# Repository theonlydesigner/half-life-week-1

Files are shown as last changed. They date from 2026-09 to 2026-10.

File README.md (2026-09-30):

# week 1: rp2040 dev board & mini hackpad

## project goals
* **Target Specs:** custom RP2040 microcontroller board using the QFN-56 package, 16MB QSPI flash, 12MHz crystal oscillator, USB-C connector with 5.1k CC pull-down resistors, and dual-row breakout headers for all GPIO pins to drive a mini hackpad.
* **Design Philosophy:** build a functional dev board from absolute ground zero using the hack club stasis guide so i finally understand what goes on under the hood of a raspberry pi pico [instead of treating microcontrollers like magic black boxes].
* **Why I'm building this:** week 1 theme is PCB, and i needed a custom board to integrate with an old mini hackpad design i had lying around. also i wanted to suffer through routing 0402 passives and tiny IC pins.

## bill of materials (BOM)
* refer to `bom.csv` in this folder for the full list of parts including the RP2040 MCU, W25Q128 flash chip, LDO voltage regulator, buttons, and passive components.

## dev journal - part 6: left-side GPIO routing (the lost footage)
* **Time spent:** 2 hours
* **Recorded on lapse:** no [because my brain shut off and i forgot to hit record]

this was easily the most painful part of the entire week. of course, this is the exact 2-hour block where i forgot to start the lapse recording, so you'll just have to take my word for it that i was working and not staring blankly at a wall.

since this was my first time designing an RP2040 board from scratch, trying to connect the RP2040 pins to the left-side GPIO headers turned into a complete trace-routing nightmare. i was following the hack club stasis guide (`stasis.hackclub.com/starter-projects/devboard`), but making clean connections for GPIO0 through GPIO15 without crossing traces or creating illegal angles felt like playing a high-stakes game of snake. 

i had to pause every 5 minutes to watch multiple youtube tutorials on KiCad trace routing, net classes, and how to use vias without making the PCB look like cheese. i kept triggering Design Rule Check (DRC) errors because my traces were either too close to the ground plane or running over decoupling capacitors. after two hours of tearing my hair out, re-routing lines three times over, and wrestling with via placements, the left side is finally connected and fully routed. 

## visual showcase

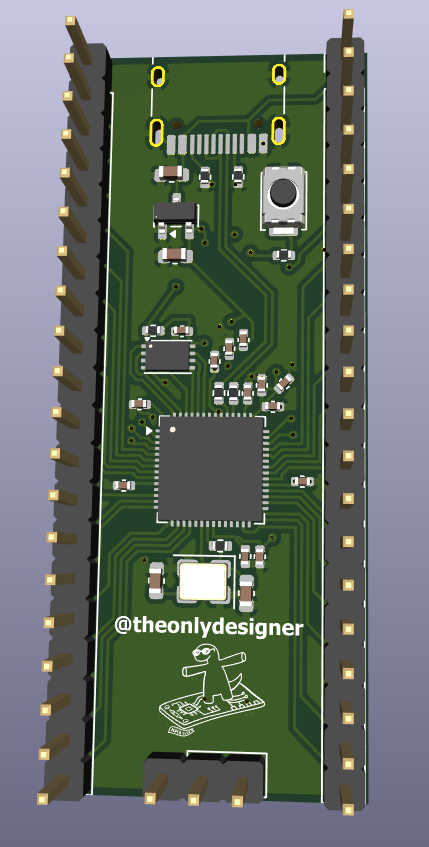
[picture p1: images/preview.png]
complete pcb layout preview

*(the fully routed RP2040 dev board before sending it off to the fab house)*

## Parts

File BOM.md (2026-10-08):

# Custom RP2040 with Hackpad – bill of materials

<!-- Generated by Half Life from project cmuo1scll00bl01lzkqmx7wfy. Edits here are overwritten on the next sync. -->
<!-- Generated: 2026-10-08T11:21:30.519Z -->

> [!NOTE]
> This parts list is mirrored from [Half Life](https://halflife.hackclub.com). Editing it here will not change the platform's copy, and the next sync overwrites this file.

| Week | Tier | Parts funding |
| --- | --- | --- |
| Week 1 | Tier 1 | $30.00 |

| Part | What it's for | Qty | Unit | Total | Vendor |
| --- | --- | --- | --- | --- | --- |
| 1uF Capacitor | — | 1 | $0.10 | $0.10 | — |
| 0.1uF Capacitor | — | 1 | $0.10 | $0.10 | — |
| 10uF Capacitor | — | 1 | $0.10 | $0.10 | — |
| 33pF Capacitor | — | 1 | $0.20 | $0.20 | — |
| USB_C_Receptacle_USB2.0_14P | — | 1 | $0.30 | $0.30 | — |
| Conn_01x20 | — | 1 | $0.60 | $0.60 | — |
| Conn_01x03 | — | 1 | $0.16 | $0.16 | — |
| 5.1K Resistor | — | 1 | $0.10 | $0.10 | — |
| 27 Resistor | — | 1 | $0.10 | $0.10 | — |
| 1K Resistor | — | 1 | $0.10 | $0.10 | — |
| 10K Resistor | — | 1 | $0.10 | $0.10 | — |
| SW_Push | — | 1 | $0.11 | $0.11 | — |
| RP2040 Chip | — | 1 | $1.30 | $1.30 | — |
| MCP1700x-330xxTT | — | 1 | $0.50 | $0.50 | — |
| W25Q128JVS | — | 1 | $5.02 | $5.02 | — |
| 12MHz Crystal | — | 1 | $0.39 | $0.39 | — |
| PCB w/ Stencil | — | 1 | $10.00 | $10.00 | — |
| Solder Paste | — | 1 | $3.00 | $3.00 | — |
| **Parts subtotal** | — | — | — | **$22.28** | — |
| **Tax & shipping** | — | — | — | **$0.00** | — |
| **Total** | — | — | — | **$22.28** | — |

$7.72 left of the tier's funding.

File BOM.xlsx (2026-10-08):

Part | Quantity | Price | Total Price(With Shipping)
1uF Capacitor | 2 | 0.1 | 0.1
0.1uF Capacitor | 11 | 0.1 | 0.1
10uF Capacitor | 2 | 0.1 | 0.1
33pF Capacitor | 2 | 0.2 | 0.2
USB_C_Receptacle_USB2.0_14P | 1 | 0.3 | 0.3
Conn_01x20 | 2 | 0.6 | 0.6
Conn_01x03 | 1 | 0.16 | 0.16
5.1K Resistor | 2 | 0.1 | 0.1
27 Resistor | 2 | 0.1 | 0.1
1K Resistor | 2 | 0.1 | 0.1
10K Resistor | 1 | 0.1 | 0.1
SW_Push | 1 | 0.11 | 0.11
RP2040 Chip | 1 | 0.84 | 1.3
MCP1700x-330xxTT | 1 | 0.5 | 0.5
W25Q128JVS | 1 | 5.02 | 5.02
12MHz Crystal | 1 | 0.39 | 0.39
PCB w/ Stencil | 1 | 6 | 10
Solder Paste | 1 | 2.3 | 3
Tweezers | 1 | 1.8 | 1.8
Solder Iron and stuff related to that | 1 | 3.2 | 3.2
 |  |  | Total Cost:
 |  |  | 27.28

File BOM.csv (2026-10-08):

Part | Quantity | No of items in 1 unit | Price w/o shipping | Price
1uF Capacitor | 1 | 2 | 0.1 | 0.1
0.1uF Capacitor | 1 | 11 | 0.1 | 0.1
10uF Capacitor | 1 | 2 | 0.1 | 0.1
33pF Capacitor | 1 | 2 | 0.2 | 0.2
USB_C_Receptacle_USB2.0_14P | 1 | 1 | 0.3 | 0.3
Conn_01x20 | 1 | 2 | 0.6 | 0.6
Conn_01x03 | 1 | 1 | 0.16 | 0.16
5.1K Resistor | 1 | 2 | 0.1 | 0.1
27 Resistor | 1 | 2 | 0.1 | 0.1
1K Resistor | 1 | 2 | 0.1 | 0.1
10K Resistor | 1 | 1 | 0.1 | 0.1
SW_Push | 1 | 1 | 0.11 | 0.11
RP2040 Chip | 1 | 1 | 0.84 | 1.3
MCP1700x-330xxTT | 1 | 1 | 0.5 | 0.5
W25Q128JVS | 1 | 1 | 5.02 | 5.02
12MHz Crystal | 1 | 1 | 0.39 | 0.39
PCB w/ Stencil | 1 | 1 | 6 | 10
Solder Paste | 1 | 1 | 2.3 | 3
Tweezers | 1 | 1 | 1.8 | 1.8
Solder Iron and stuff related to that | 1 | 1 | 3.2 | 3.2

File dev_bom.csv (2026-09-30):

Comment | Designator | Footprint | Quantity | LCSC Part Number
1uF | C1, C10 | C_0402_1005Metric | 2
0.1uF | C2, C3, C4, C5, C6, C7, C8, C9, C11, C12, C17 | C_0402_1005Metric | 11
10uF | C13, C14 | C_0603_1608Metric | 2
33pF | C15, C16 | C_0603_1608Metric | 2
USB_C_Receptacle_USB2.0_14P | J1 | USB_C_Receptacle_HRO_TYPE-C-31-M-12 | 1
Conn_01x20 | J2, J3 | PinHeader_1x20_P2.54mm_Vertical | 2
Conn_01x03 | J4 | PinHeader_1x03_P2.54mm_Vertical | 1
5.1K | R1, R2 | R_0402_1005Metric | 2
27 | R3, R4 | R_0402_1005Metric | 2
1K | R5, R6 | R_0402_1005Metric | 2
10K | R7 | R_0402_1005Metric | 1
SW_Push | SW1 | SW_Push_SPST_NO_Alps_SKRK | 1
RP2040 | U1 | QFN-56-1EP_7x7mm_P0.4mm_EP3.2x3.2mm | 1
MCP1700x-330xxTT | U2 | SOT-23 | 1
W25Q128JVS | U4 | Winbond_USON-8-1EP_3x2mm_P0.5mm_EP0.2x1.6mm | 1
12MHz | Y1 | Crystal_SMD_3225-4Pin_3.2x2.5mm | 1

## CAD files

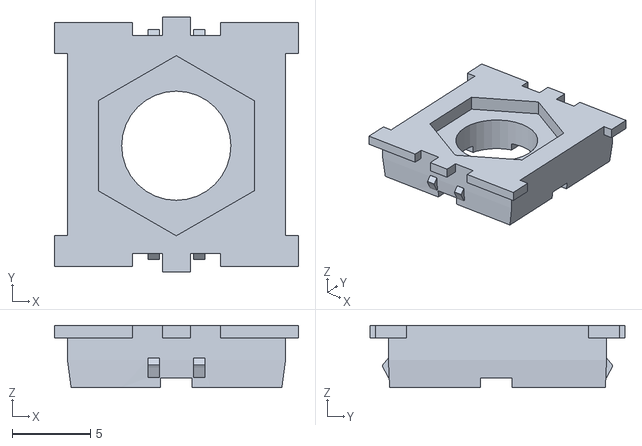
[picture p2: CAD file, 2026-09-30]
3D files/EC11_to_MX_Adapter_V2.stl
15.6 x 16.3 x 4.00

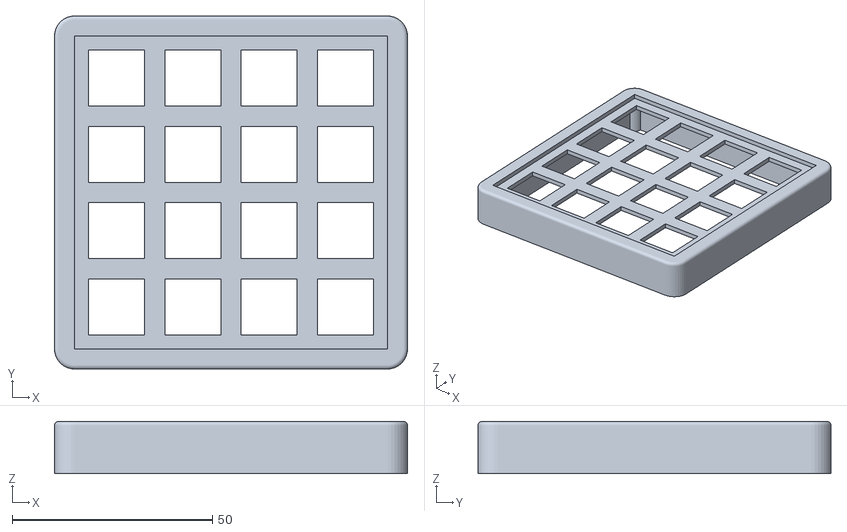
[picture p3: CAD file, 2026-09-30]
3D files/stl/Top.stl
88.2 x 88.2 x 13.0

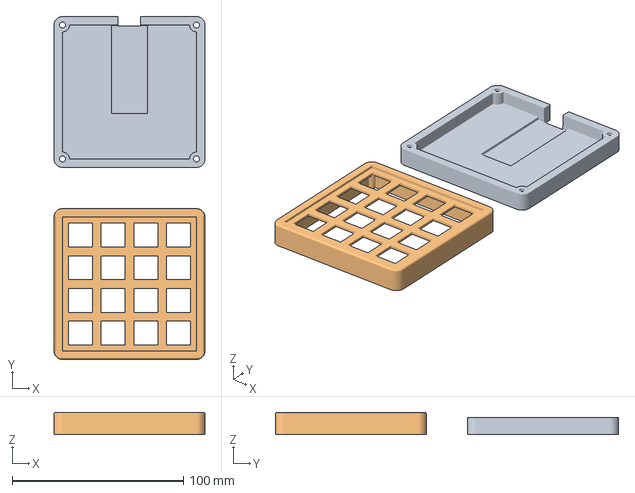
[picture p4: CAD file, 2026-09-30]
3D files/case.3mf
88.2 x 200.4 x 13.0 mm
Bottom
Top

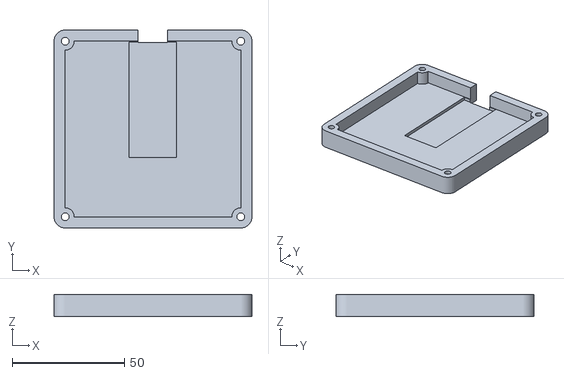
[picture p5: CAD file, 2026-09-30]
3D files/stl/Bottom.stl
88.2 x 88.2 x 10.0

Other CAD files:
3D files/case.f3d

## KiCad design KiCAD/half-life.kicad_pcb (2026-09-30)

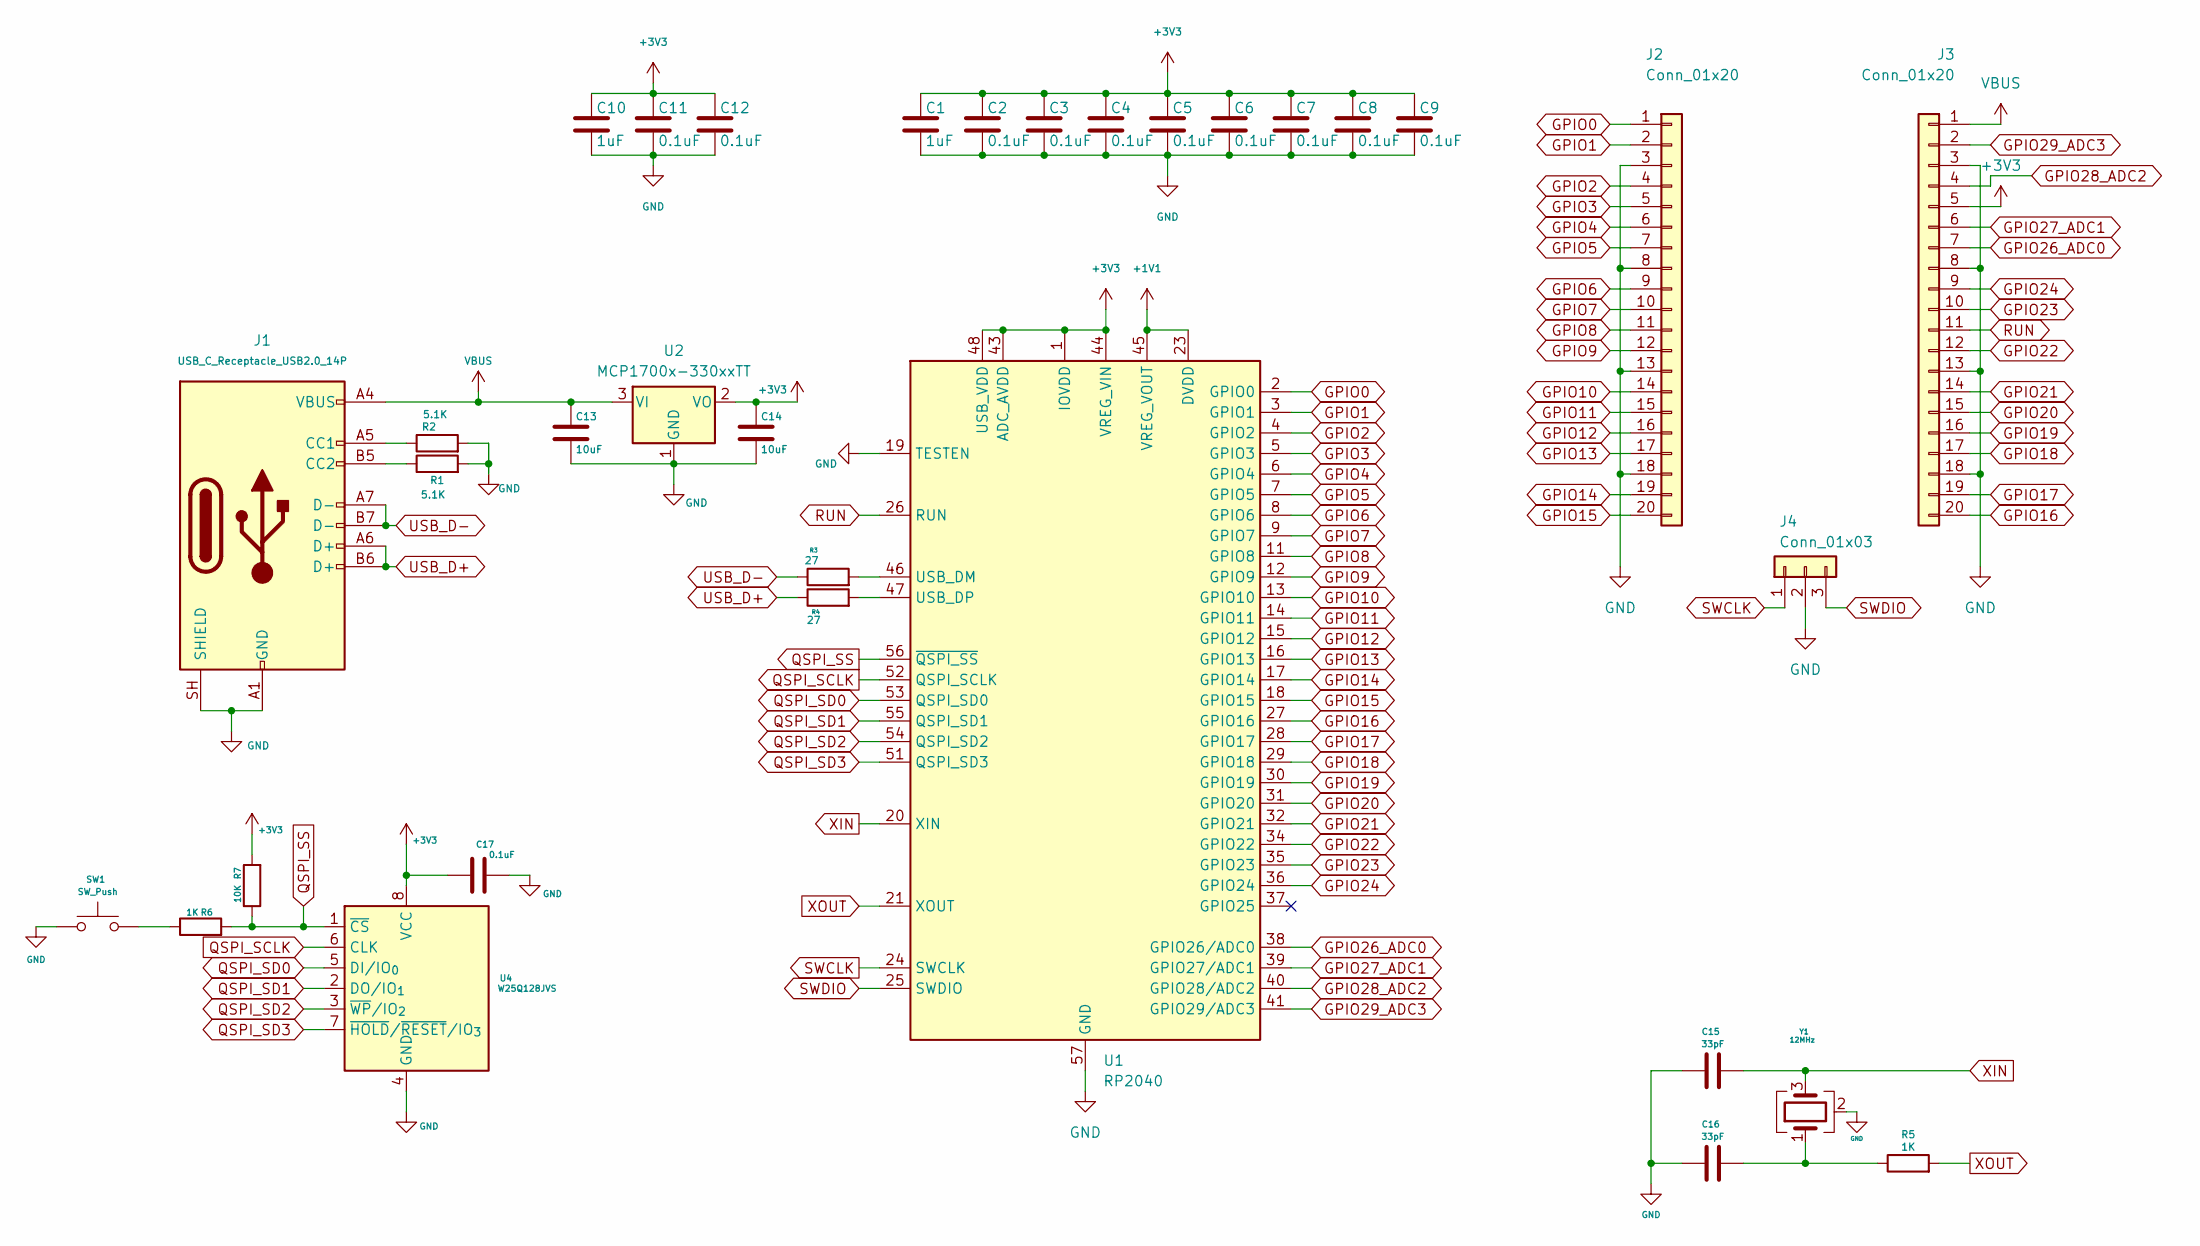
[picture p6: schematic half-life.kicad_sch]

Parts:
C1, C10: 1uF; C_0402_1005Metric
C2, C3, C4, C5, C6, C7, C8, C9, C11, C12, C17: 0.1uF; C_0402_1005Metric
C13, C14: 10uF; C_0603_1608Metric
C15, C16: 33pF; C_0603_1608Metric
J1: USB_C_Receptacle_USB2.0_14P; USB_C_Receptacle_HRO_TYPE-C-31-M-12
J2, J3: Conn_01x20; PinHeader_1x20_P2.54mm_Vertical
J4: Conn_01x03; PinHeader_1x03_P2.54mm_Vertical
R1, R2: 5.1K; R_0402_1005Metric
R3, R4: 27; R_0402_1005Metric
R5, R6: 1K; R_0402_1005Metric
R7: 10K; R_0402_1005Metric
SW1: SW_Push; SW_Push_SPST_NO_Alps_SKRK
U1: RP2040; QFN-56-1EP_7x7mm_P0.4mm_EP3.2x3.2mm
U2: MCP1700x-330xxTT; SOT-23
U4: W25Q128JVS; Winbond_USON-8-1EP_3x2mm_P0.5mm_EP0.2x1.6mm
Y1: 12MHz; Crystal_SMD_3225-4Pin_3.2x2.5mm

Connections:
+1V1: U1.23 (DVDD), U1.45 (VREG_VOUT), U1.50 (DVDD)
+3V3: C1.1, C2.1, C3.1, C4.1, C5.1, C6.1, C7.1, C8.1, C9.1, C10.1, C11.1, C12.1, C14.1, C17.1, J3.5, R7.2, U1.1 (IOVDD), U1.10 (IOVDD), U1.22 (IOVDD), U1.33 (IOVDD), U1.42 (IOVDD), U1.43 (ADC_AVDD), U1.44 (VREG_VIN), U1.48 (USB_VDD), U1.49 (IOVDD), U2.2 (VO), U4.8 (VCC)
GND: C1.2, C2.2, C3.2, C4.2, C5.2, C6.2, C7.2, C8.2, C9.2, C10.2, C11.2, C12.2, C13.2, C14.2, C15.1, C16.1, C17.2, J1.A1 (GND), J1.A12 (GND), J1.B1 (GND), J1.B12 (GND), J1.SH (SHIELD), J2.3, J2.8, J2.13, J2.18, J3.3, J3.8, J3.13, J3.18, J4.2, R1.2, R2.2, SW1.1, U1.19 (TESTEN), U1.57 (GND), U2.1 (GND), U4.4 (GND), Y1.2 (G), Y1.4 (G)
GPIO0: J2.1, U1.2 (GPIO0)
GPIO1: J2.2, U1.3 (GPIO1)
GPIO2: J2.4, U1.4 (GPIO2)
GPIO3: J2.5, U1.5 (GPIO3)
GPIO4: J2.6, U1.6 (GPIO4)
GPIO5: J2.7, U1.7 (GPIO5)
GPIO6: J2.9, U1.8 (GPIO6)
GPIO7: J2.10, U1.9 (GPIO7)
GPIO8: J2.11, U1.11 (GPIO8)
GPIO9: J2.12, U1.12 (GPIO9)
GPIO10: J2.14, U1.13 (GPIO10)
GPIO11: J2.15, U1.14 (GPIO11)
GPIO12: J2.16, U1.15 (GPIO12)
GPIO13: J2.17, U1.16 (GPIO13)
GPIO14: J2.19, U1.17 (GPIO14)
GPIO15: J2.20, U1.18 (GPIO15)
GPIO16: J3.20, U1.27 (GPIO16)
GPIO17: J3.19, U1.28 (GPIO17)
GPIO18: J3.17, U1.29 (GPIO18)
GPIO19: J3.16, U1.30 (GPIO19)
GPIO20: J3.15, U1.31 (GPIO20)
GPIO21: J3.14, U1.32 (GPIO21)
GPIO22: J3.12, U1.34 (GPIO22)
GPIO23: J3.10, U1.35 (GPIO23)
GPIO24: J3.9, U1.36 (GPIO24)
GPIO26_ADC0: J3.7, U1.38 (GPIO26/ADC0)
GPIO27_ADC1: J3.6, U1.39 (GPIO27/ADC1)
GPIO28_ADC2: J3.4, U1.40 (GPIO28/ADC2)
GPIO29_ADC3: J3.2, U1.41 (GPIO29/ADC3)
unnamed: C16.2, R5.1, Y1.1
unnamed: J1.A5 (CC1), R2.1
unnamed: J1.B5 (CC2), R1.1
unnamed: R6.1, SW1.2
unnamed: R3.2, U1.46 (USB_DM)
unnamed: R4.2, U1.47 (USB_DP)
QSPI_SCLK: U1.52 (QSPI_SCLK), U4.6 (CLK)
QSPI_SD0: U1.53 (QSPI_SD0), U4.5 (DI/IO_{0})
QSPI_SD1: U1.55 (QSPI_SD1), U4.2 (DO/IO_{1})
QSPI_SD2: U1.54 (QSPI_SD2), U4.3 (~WP/IO_{2})
QSPI_SD3: U1.51 (QSPI_SD3), U4.7 (~HOLD/~RESET/IO_{3})
QSPI_SS: R6.2, R7.1, U1.56 (~QSPI_SS), U4.1 (~CS)
RUN: J3.11, U1.26 (RUN)
SWCLK: J4.1, U1.24 (SWCLK)
SWDIO: J4.3, U1.25 (SWDIO)
USB_D+: J1.A6 (D+), J1.B6 (D+), R4.1
USB_D-: J1.A7 (D-), J1.B7 (D-), R3.1
VBUS: C13.1, J1.A4 (VBUS), J1.A9 (VBUS), J1.B4 (VBUS), J1.B9 (VBUS), J3.1, U2.3 (VI)
XIN: C15.2, U1.20 (XIN), Y1.3
XOUT: R5.2, U1.21 (XOUT)

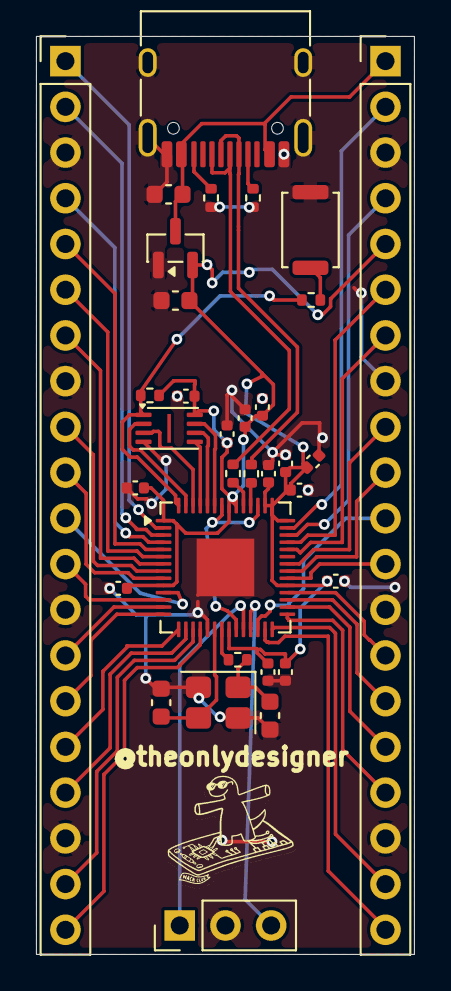
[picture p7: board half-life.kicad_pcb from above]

Board: 2 copper layers, 21.0 x 51.0 mm, 33 parts (0 on the bottom side), 52 nets.

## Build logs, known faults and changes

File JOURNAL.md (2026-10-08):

# Custom RP2040 with Hackpad – devlog

<!-- Generated by Half Life from project cmuo1scll00bl01lzkqmx7wfy. Edits here are overwritten on the next sync. -->
<!-- Generated: 2026-10-07T16:08:36.950Z -->

> [!NOTE]
> This devlog is mirrored from [Half Life](https://halflife.hackclub.com). Editing it here will not change the platform's copy, and the next sync overwrites this file.

> This is a custom devboard which is used in a hackpad.

| Week | Tier | Hours logged | Entries |
| --- | --- | --- | --- |
| Week 1 | Tier 1 | 10.18h | 13 |

## Contents

1. [2026-10-07 – Work session](#2026-10-07-work-session)
2. [2026-10-07 – Work session](#2026-10-07-work-session)
3. [2026-10-07 – Work session](#2026-10-07-work-session)
4. [2026-10-07 – Work session](#2026-10-07-work-session)
5. [2026-10-07 – Work session](#2026-10-07-work-session)
6. [2026-10-07 – ](#2026-10-07-1000133429httpshalflifehackclub-assetscomhackclub)
7. [2026-10-07 – Work session](#2026-10-07-work-session)
8. [2026-10-07 – Work session](#2026-10-07-work-session)
9. [2026-10-07 – Work session](#2026-10-07-work-session)
10. [2026-10-07 – Work session](#2026-10-07-work-session)
11. [2026-10-07 – Work session](#2026-10-07-work-session)
12. [2026-10-07 – Work session](#2026-10-07-work-session)
13. [2026-10-07 – So I finished it all off by creating the BOM and finding these freaking components which were genuinely so hard to find that I felt like a cyber crime investigator. Also I planned making a hackpad wit](#2026-10-07-so-i-finished-it-all-off-by-creating-the-bom-and-)

## Design

### 2026-10-07 – Work session

**0.8h**

[Timelapse](https://lookout.hackclub.com/api/media/269a9ae2-2f54-47e3-90a6-ad32681b4d10/video.mp4)

### 2026-10-07 – Work session

**0.25h**

[Timelapse](https://lookout.hackclub.com/api/media/8c4b389f-63ab-4df3-a1fd-251f6097bf4c/video.mp4)

### 2026-10-07 – Work session

**0.23h**

[Timelapse](https://lookout.hackclub.com/api/media/d9df902d-8b3c-43a0-b24e-54f84b571e70/video.mp4)

### 2026-10-07 – Work session

**0.17h**

[Timelapse](https://lookout.hackclub.com/api/media/ee675750-b7da-438b-a682-8e0a150c754e/video.mp4)

### 2026-10-07 – Work session

**1.5h**

[Timelapse](https://lookout.hackclub.com/api/media/0f32a795-2545-478b-b557-681a24d7bb3d/video.mp4)

### 2026-10-07 – 

**2h**





this was easily the most painful part of the entire week. of course, this is the exact 2-hour block where i forgot to start the lapse recording, so you'll just have to take my word for it that i was working and not staring blankly at a wall.

since this was my first time designing an RP2040 board from scratch, trying to connect the RP2040 pins to the left-side GPIO headers turned into a complete trace-routing nightmare. i was following the hack club stasis guide, but making clean connections for GPIO0 through GPIO15 without crossing traces or creating illegal angles felt like playing a high-stakes game of snake.

i had to pause every 5 minutes to watch multiple youtube tutorials on KiCad trace routing, net classes and how to use vias without making the PCB look like cheese. i kept triggering Design Rule Check (DRC) errors because my traces were either too close to the ground plane or running over decoupling capacitors. after two hours of tearing my hair out, re-routing lines three times over and wrestling with via placements, the left side is finally connected and fully routed.

### 2026-10-07 – Work session

**0.55h**

[Timelapse](https://lookout.hackclub.com/api/media/dbf397d8-f065-45ef-9b4d-df3f0a35d00e/video.mp4)

### 2026-10-07 – Work session

**0.55h**

[Timelapse](https://lookout.hackclub.com/api/media/ce9258ec-6ad9-4751-8cf8-02ce0b6c5e7e/video.mp4)

### 2026-10-07 – Work session

**0.65h**

[Timelapse](https://lookout.hackclub.com/api/media/10de7fd2-a9c0-4949-a5f2-423b0b1ae599/video.mp4)

### 2026-10-07 – Work session

**0.82h**

[Timelapse](https://lookout.hackclub.com/api/media/75b58998-976e-44d1-9c34-e4ab08120736/video.mp4)

### 2026-10-07 – Work session

**0.43h**

[Timelapse](https://lookout.hackclub.com/api/media/ba1b83b3-4d2b-42df-8b29-47f84c1282d5/video.mp4)

### 2026-10-07 – Work session

**0.53h**

[Timelapse](https://lookout.hackclub.com/api/media/12752c48-7398-4bda-996c-5bd7914e9018/video.mp4)

### 2026-10-07 – So I finished it all off by creating the BOM and finding these freaking components which were genuinely so hard to find that I felt like a cyber crime investigator. Also I planned making a hackpad wit

**1.7h**

So I finished it all off by creating the BOM and finding these freaking components which were genuinely so hard to find that I felt like a cyber crime investigator. Also I planned making a hackpad with this devboard but I soon realised I won't get enough grant to make it so I dropped the idea unfortunately after finding all the resources for it. I then wrote the readme files and organised the project structure.





Overall I'm pretty happy with how this project turned out. Now let's see what we face in building.

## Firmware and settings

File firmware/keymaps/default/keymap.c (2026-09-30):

#include QMK_KEYBOARD_H
#include "timer.h"

#define NUM_MACROS 16
#define MAX_MACRO_LEN 64
#define NUM_LAYERS 16
#define MAX_MACRO_KEYS 6
#define RAW_HID_FRAGMENT_BUFFER_SIZE 512

#define SET_ENCODER_COMMAND 0
#define SET_MACRO_COMMAND 1
#define SET_REPEATING_MACRO_COMMAND 2

typedef struct
{
    uint16_t keys[MAX_MACRO_KEYS];
    uint8_t key_count;
} macro_t;

macro_t macros[NUM_LAYERS][NUM_MACROS][MAX_MACRO_LEN];
uint8_t macro_len[NUM_LAYERS][NUM_MACROS];
int16_t macro_repeating[NUM_LAYERS][NUM_MACROS];

uint16_t encoder_actions[NUM_LAYERS][2];

uint8_t packet_buffer[RAW_HID_FRAGMENT_BUFFER_SIZE];
uint8_t expected_transaction_id = 0;
uint8_t expected_fragments = 0;
uint8_t received_fragments = 0;
uint16_t packet_buffer_length = 0;
bool fragment_transaction_active = false;

enum custom_keycodes
{
    SWITCH_LAYER_0 = SAFE_RANGE,
    SWITCH_LAYER_1,
    SWITCH_LAYER_2,
    SWITCH_LAYER_3,
    SWITCH_LAYER_4,
    SWITCH_LAYER_5,
    SWITCH_LAYER_6,
    SWITCH_LAYER_7,
    SWITCH_LAYER_8,
    SWITCH_LAYER_9,
    SWITCH_LAYER_10,
    SWITCH_LAYER_11,
    SWITCH_LAYER_12,
    SWITCH_LAYER_13,
    SWITCH_LAYER_14,
    SWITCH_LAYER_15
};

void load_default_macros(void)
{
    for (uint8_t l = 0; l < NUM_LAYERS; l++)
    {
        for (uint8_t m = 0; m < NUM_MACROS; m++)
        {
            macros[l][m][0].keys[0] = KC_NO;
            macros[l][m][0].key_count = 0;
            macro_len[l][m] = 0;
            macro_repeating[l][m] = -1;
        }

        macros[l][0][0].keys[0] = KC_MPRV;
        macros[l][0][0].key_count = 1;
        macro_len[l][0] = 1;
        macros[l][1][0].keys[0] = KC_MPLY;
        macros[l][1][0].key_count = 1;
        macro_len[l][1] = 1;
        macros[l][2][0].keys[0] = KC_MNXT;
        macros[l][2][0].key_count = 1;
        macro_len[l][2] = 1;
        macros[l][3][0].keys[0] = SWITCH_LAYER_0;
        macros[l][3][0].key_count = 1;
        macro_len[l][3] = 1;
        macros[l][4][0].keys[0] = KC_F13;
        macros[l][4][0].key_count = 1;
        macro_len[l][4] = 1;
        macros[l][5][0].keys[0] = KC_F14;
        macros[l][5][0].key_count = 1;
        macro_len[l][5] = 1;
        macros[l][6][0].keys[0] = KC_F15;
        macros[l][6][0].key_count = 1;
        macro_len[l][6] = 1;
        macros[l][7][0].keys[0] = KC_MUTE;
        macros[l][7][0].key_count = 1;
        macro_len[l][7] = 1;
        macros[l][8][0].keys[0] = KC_F16;
        macros[l][8][0].key_count = 1;
        macro_len[l][8] = 1;
        macros[l][9][0].keys[0] = KC_F17;
        macros[l][9][0].key_count = 1;
        macro_len[l][9] = 1;
        macros[l][10][0].keys[0] = KC_F18;
        macros[l][10][0].key_count = 1;
        macro_len[l][10] = 1;
        macros[l][11][0].keys[0] = MS_BTN1;
        macros[l][11][0].key_count = 1;
        macro_len[l][11] = 1;
        macro_repeating[l][11] = 100;
        macros[l][12][0].keys[0] = SWITCH_LAYER_1;
        macros[l][12][0].key_count = 1;
        macro_len[l][12] = 1;
        macros[l][13][0].keys[0] = SWITCH_LAYER_2;
        macros[l][13][0].key_count = 1;
        macro_len[l][13] = 1;
        macros[l][14][0].keys[0] = SWITCH_LAYER_3;
        macros[l][14][0].key_count = 1;
        macro_len[l][14] = 1;
        macros[l][15][0].keys[0] = SWITCH_LAYER_4;
        macros[l][15][0].key_count = 1;
        macro_len[l][15] = 1;
    }
    encoder_actions[0][0] = KC_VOLD;
    encoder_actions[0][1] = KC_VOLU;
    encoder_actions[1][0] = KC_LEFT;
    encoder_actions[1][1] = KC_RIGHT;
    encoder_actions[2][0] = C(KC_MINS);
    encoder_actions[2][1] = C(KC_EQL);
    encoder_actions[3][0] = MS_WHLD;
    encoder_actions[3][1] = MS_WHLU;
    encoder_actions[4][0] = KC_MPRV;
    encoder_actions[4][1] = KC_MNXT;
    for (uint8_t l = 5; l < NUM_LAYERS; l++)
    {
        encoder_actions[l][0] = KC_VOLD;
        encoder_actions[l][1] = KC_VOLU;
    }
}

void keyboard_post_init_user(void)
{
    load_default_macros();
}

bool encoder_update_user(uint8_t index, bool clockwise)
{
    if (index != 0)
        return false;
    uint8_t layer = get_highest_layer(layer_state);
    if (layer >= NUM_LAYERS)
        layer = 0;
    uint16_t action = encoder_actions[layer][clockwise ? 1 : 0];
    tap_code16(action);
    return false;
}

bool consume_macro_keycodes(uint8_t layer, uint8_t macro_index, uint8_t macro_length, const uint8_t **data_ptr, const uint8_t *data_end)
{
    for (uint8_t i = 0; i < macro_length && i < MAX_MACRO_LEN; i++)
    {
        if (*data_ptr >= data_end)
        {
            printf("Received truncated macro update for layer %d, macro %d\n", layer, macro_index);
            return false;
        }

        uint8_t actions_length = (*data_ptr)[0];
        macros[layer][macro_index][i].key_count = actions_length;
        printf("Macro has %d actions\n", actions_length);
        (*data_ptr)++;

        for (uint8_t j = 0; j < actions_length && j < MAX_MACRO_KEYS; j++)
        {
            if ((*data_ptr) + 1 >= data_end)
            {
                printf("Received truncated keycode list for layer %d, macro %d, action %d\n", layer, macro_index, i);
                return false;
            }

            uint16_t keycode = ((uint16_t)(*data_ptr)[0] << 8) | (*data_ptr)[1];
            printf("Reading keycode for layer %d, macro %d, action %d: 0x%04x\n", layer, macro_index, i, keycode);
            macros[layer][macro_index][i].keys[j] = keycode;
            (*data_ptr) += 2;
        }
    }

    return true;
}

void apply_macro_update_payload(const uint8_t *data, uint16_t length)
{
    if (length < 3)
    {
        printf("Received invalid macro update payload (length %d)\n", length);
        return;
    }

    uint8_t layer = data[0];
    uint8_t macro_index = data[1];
    uint8_t macro_length = data[2];

    printf("Received macro update for layer %d, macro %d, length %d\n", layer, macro_index, macro_length);

    if (layer < NUM_LAYERS && macro_index < NUM_MACROS && macro_length <= MAX_MACRO_LEN)
    {
        macro_len[layer][macro_index] = macro_length;
        const uint8_t *data_ptr = &data[3];
        consume_macro_keycodes(layer, macro_index, macro_length, &data_ptr, data + length);
    }
}

void reset_fragment_transaction(void)
{
    fragment_transaction_active = false;
    packet_buffer_length = 0;
    expected_transaction_id = 0;
    expected_fragments = 0;
    received_fragments = 0;
}
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

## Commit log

2026-09-30 Put all the files in the root projectory
    [BOM.csv, BOM.xlsx, Bottom.stl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]
2026-10-08 Update BOM.csv by removing components
    Removed several components from the BOM and adjusted the total cost.
    [BOM.csv]
2026-10-08 Update PCB w/ Stencil pricing in BOM.csv
    [BOM.csv]
